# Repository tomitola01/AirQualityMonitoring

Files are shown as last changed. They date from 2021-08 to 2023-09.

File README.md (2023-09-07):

# Air Quality Monitoring System
This repository includes the Arduino C code (monitoring_arduinoC.ino) for the air quality monitoring system. To be used with the ESP32 microcontroller, a BME680 sensor, a push button for input, and an Adafruit 128x32 OLED. <br />
\
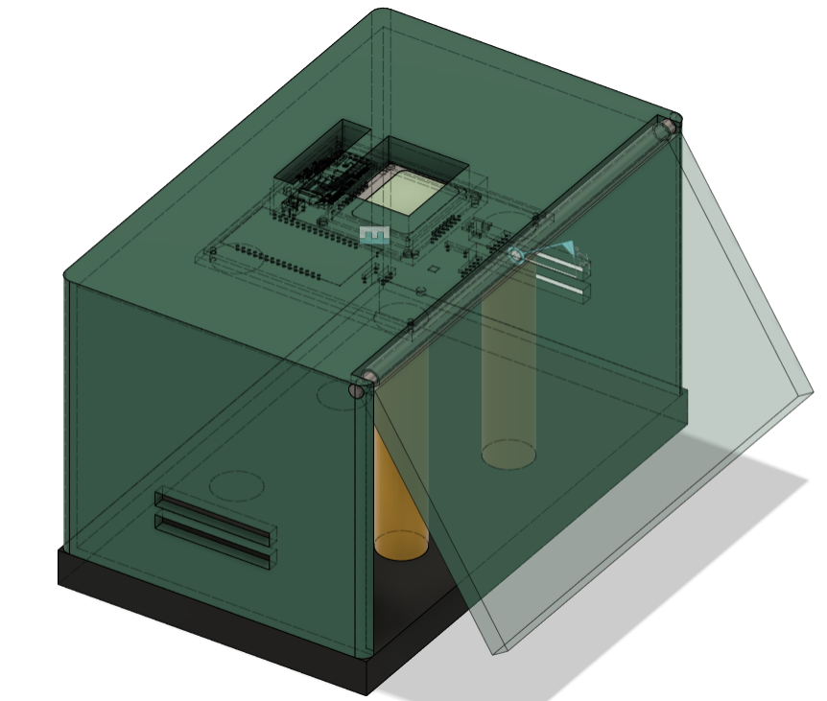
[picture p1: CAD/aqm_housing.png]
Fusion 360 design of the AQM housing
<br/>
\
Below shows the Adafruit display on the breadboard prototype with the system working as expected.
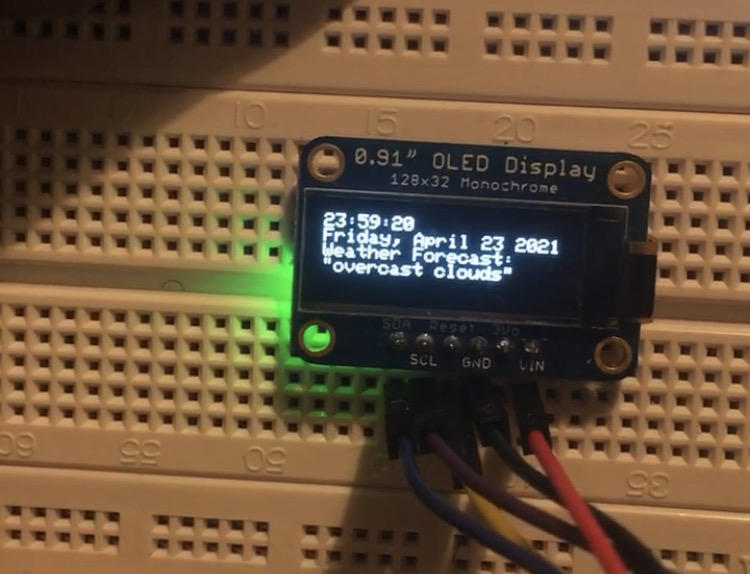
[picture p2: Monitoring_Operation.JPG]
breadboard prototype working on an Adafruit 128x32 shows an example of the system operating normally
<br/>
\
The circuit schematics and PCB for the system can be found in the circuit_files folder. <br />
The CAD folder contains the 3D design of the monitoring system housing. Fusion 360 is needed to open the .fz3 file. <br />
\
Also included is the HTML file (monitoring_webserver.html) to build the web server with the ESP32. <br />
To build the server: 
1. Download the Monitoring_Code folder
2. Open the project using Ardunio
3. Upload the sketch to the ESP32 and run it
4. Open the serial monitor and use obtain the ESP32's IP address
5. Enter IP address into web browser

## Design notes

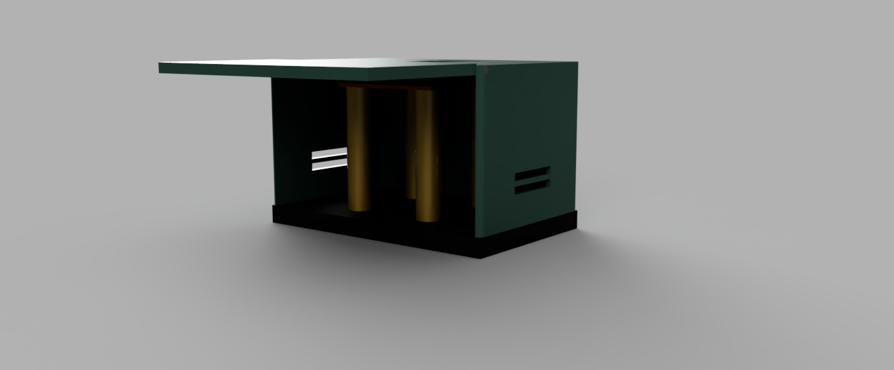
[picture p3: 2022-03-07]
CAD/render.png

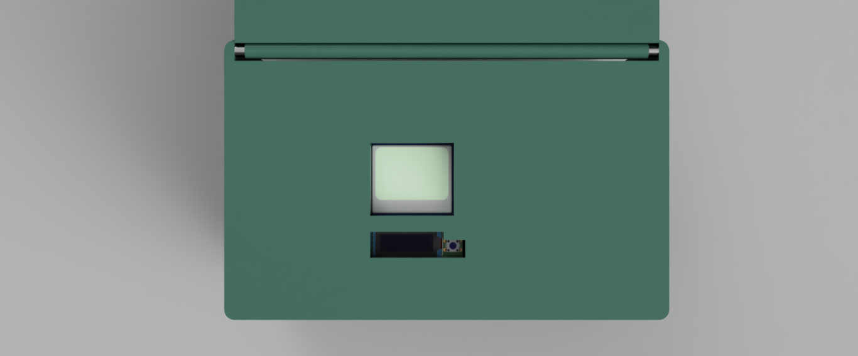
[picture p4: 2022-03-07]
CAD/top render.png

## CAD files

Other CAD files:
CAD/MonitorHousing v15.f3z

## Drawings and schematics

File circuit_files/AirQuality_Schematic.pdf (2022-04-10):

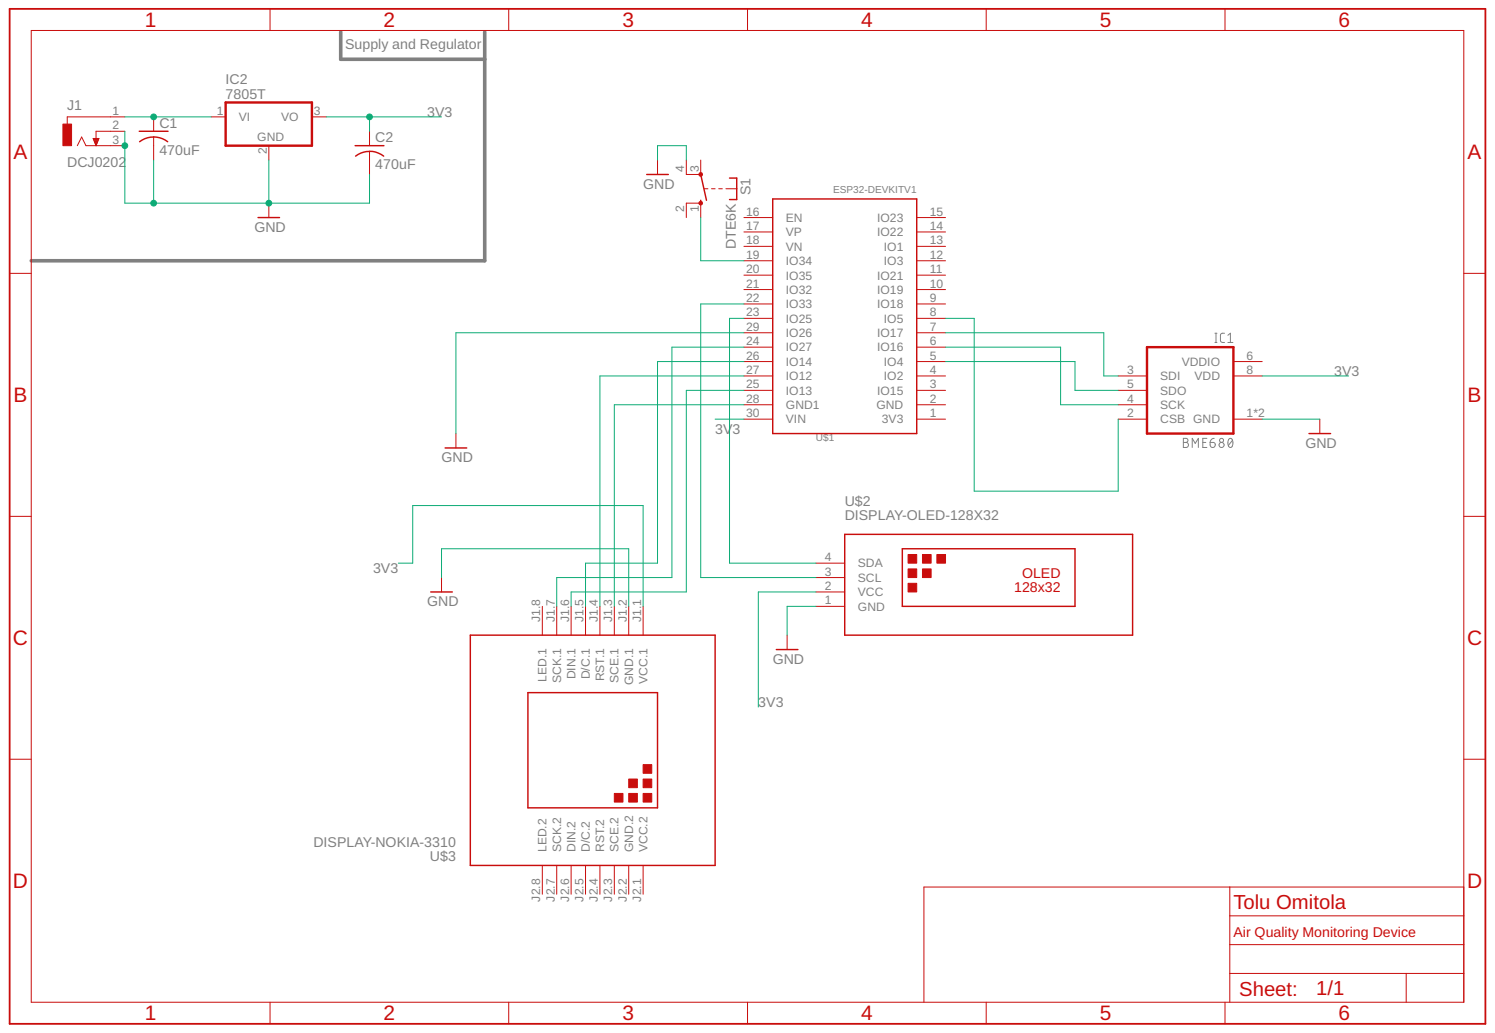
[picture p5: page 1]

IC2 7805T | Supply and Regulator

23 | 8
29 | 7
24 | 6

Air Quality Monitoring Device

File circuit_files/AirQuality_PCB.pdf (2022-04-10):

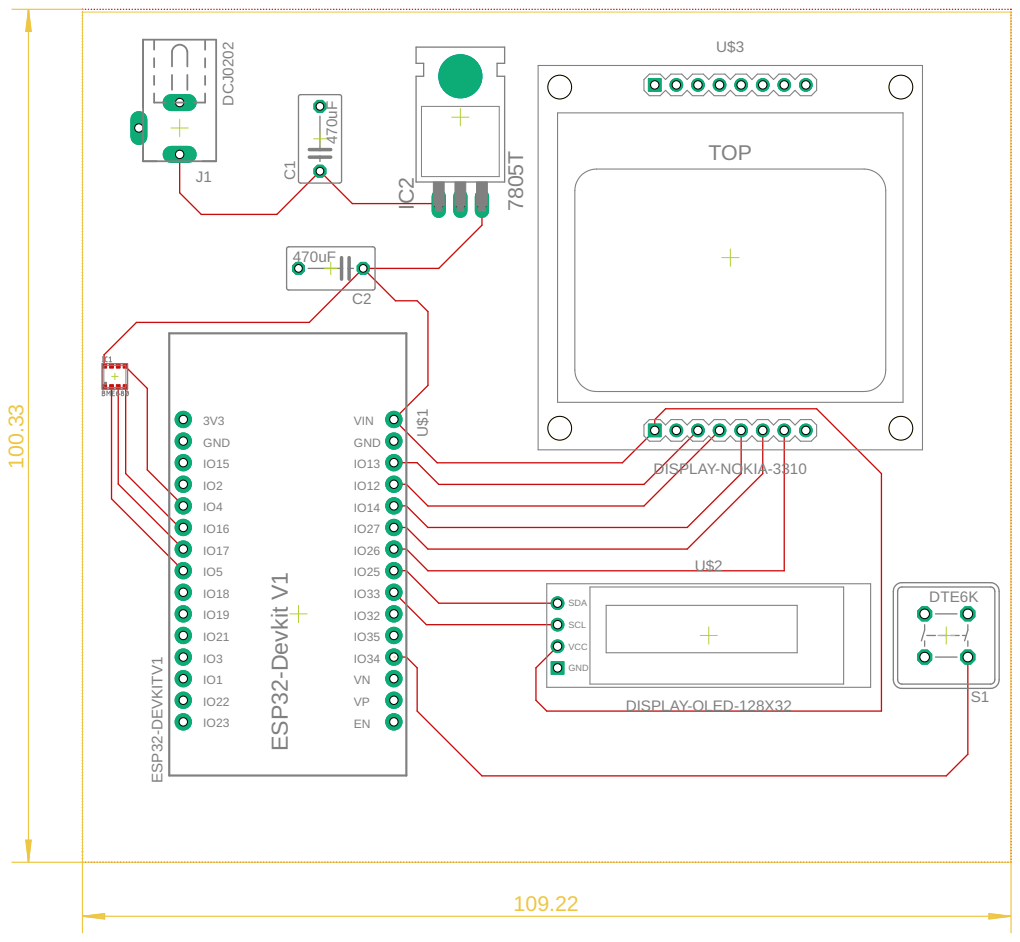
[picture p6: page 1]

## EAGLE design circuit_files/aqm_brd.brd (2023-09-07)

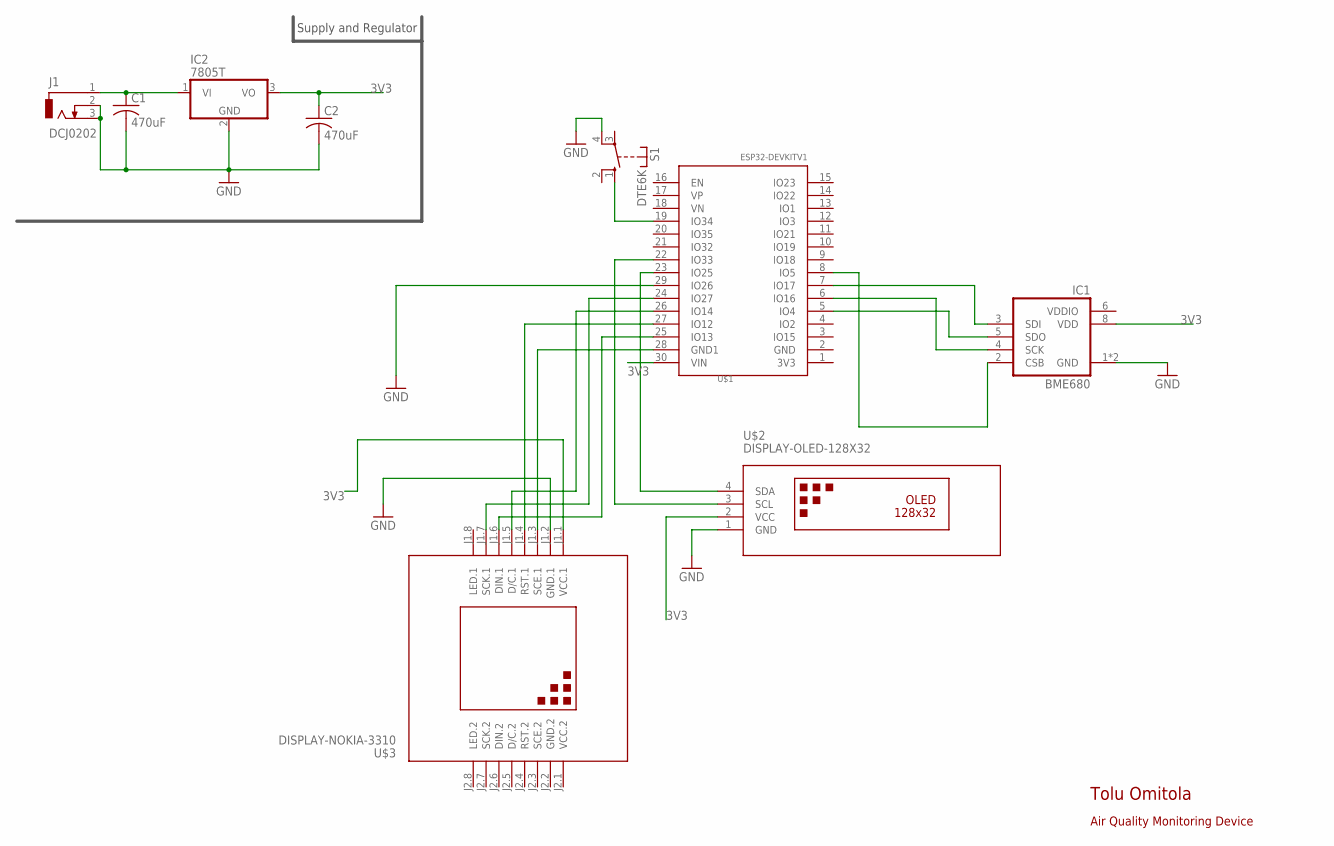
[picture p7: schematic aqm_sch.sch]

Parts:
C1, C2: 470uF; C075-052X106
IC1: BME680
IC2: 7805T; TO220H
J1: DCJ0202
S1: DTE6K
U$1: ESP32DEVKITV1; ESP32-DEVKITV1
U$2: DISPLAY-OLED-128X32
U$3: DISPLAY-NOKIA-3310

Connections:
3V3: C2.1, IC1.8 (VDD), IC2.3 (VO), U$1.30 (VIN), U$2.2 (VCC), U$3.J1.1 (VCC.1)
GND: C1.2, C2.2, IC1.1 (GND), IC1.7 (GND), IC2.2 (GND), J1.2, J1.3, S1.4, U$1.29 (IO26), U$2.1 (GND), U$3.J1.2 (GND.1)
GND.2: U$3.J2.2 (GND.2)
unnamed: U$1.26 (IO14), U$3.J1.5 (D/C.1)
unnamed: U$1.28 (GND1), U$3.J1.3 (SCE.1)
unnamed: U$1.24 (IO27), U$3.J1.7 (SCK.1)
unnamed: U$1.25 (IO13), U$3.J1.6 (DIN.1)
unnamed: C1.1, IC2.1 (VI), J1.1
unnamed: U$1.23 (IO25), U$2.4 (SDA)
unnamed: IC1.2 (CSB), U$1.8 (IO5)
unnamed: U$1.22 (IO33), U$2.3 (SCL)
unnamed: IC1.4 (SCK), U$1.6 (IO16)
unnamed: IC1.5 (SDO), U$1.5 (IO4)
unnamed: U$1.27 (IO12), U$3.J1.4 (RST.1)
unnamed: IC1.3 (SDI), U$1.7 (IO17)
unnamed: S1.1 (S), U$1.19 (IO34)
VCC.2: U$3.J2.1 (VCC.2)
VDDIO: IC1.6 (VDDIO)

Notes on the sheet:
Supply and Regulator
Tolu Omitola
Air Quality Monitoring Device

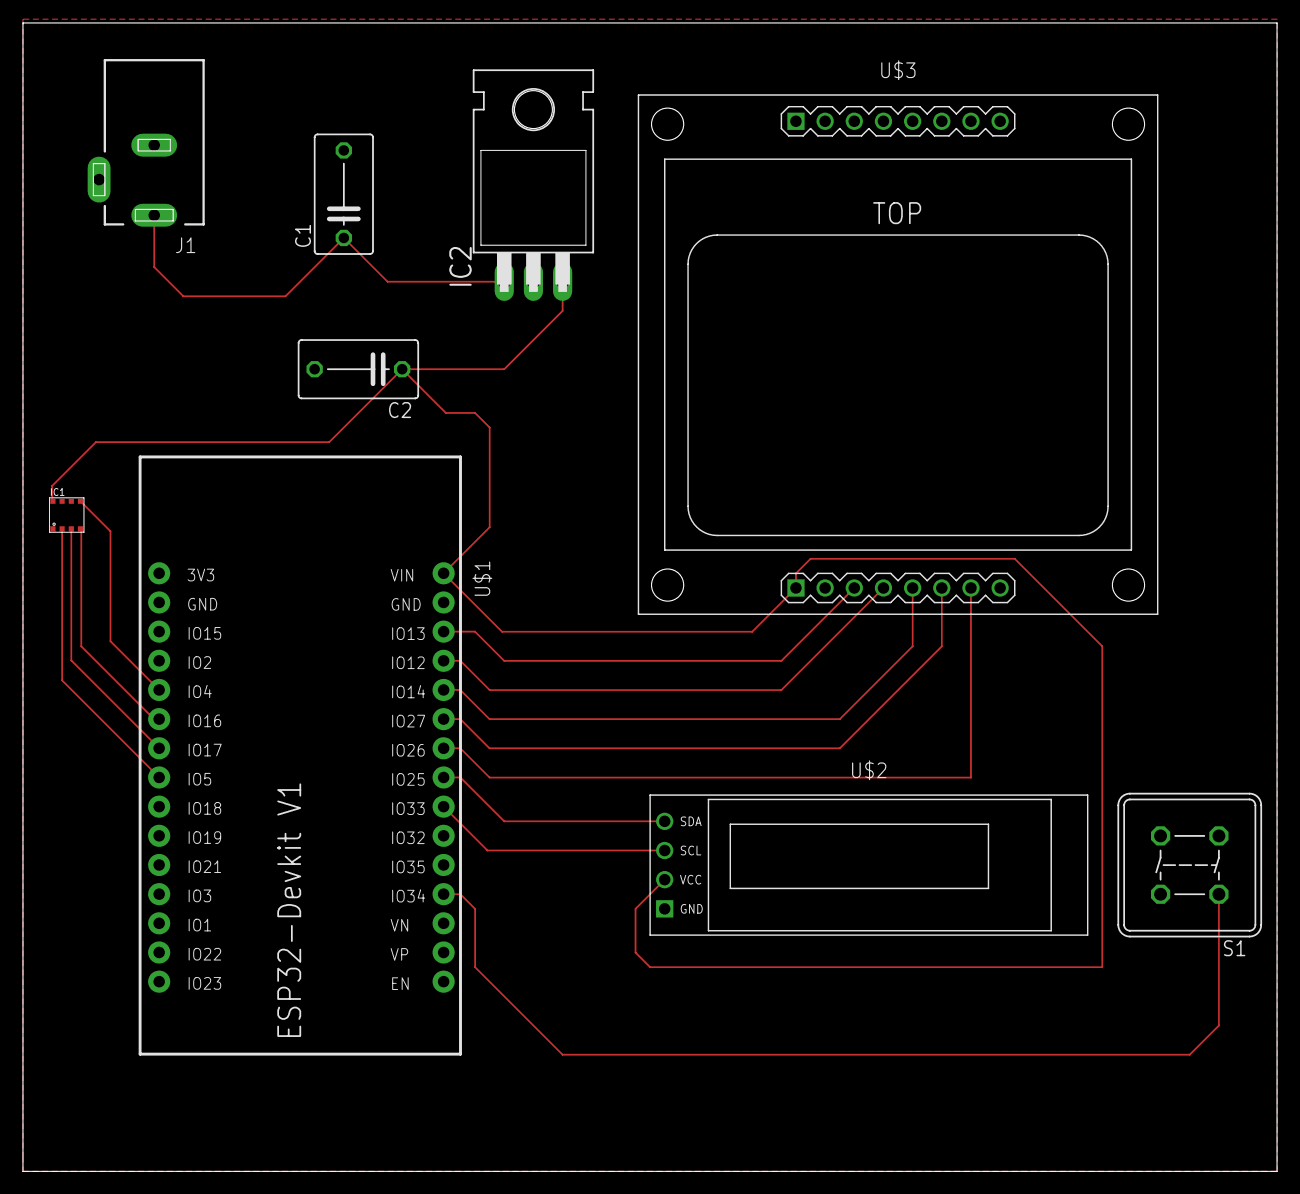
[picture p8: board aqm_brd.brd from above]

Board: 2 copper layers, 109.2 x 100.0 mm, 9 parts (0 on the bottom side), 15 nets.

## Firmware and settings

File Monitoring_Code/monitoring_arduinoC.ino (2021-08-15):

/*
  Code for air quality monitoring system.
  Code heavily adapted using guides from https://randomnerdtutorials.com/projects-esp32/
*/

//libraries included
#include <Wire.h>
#include <SPI.h>
#include <SPIFFS.h>
#include <Adafruit_Sensor.h>
#include "Adafruit_BME680.h"
#include <WiFi.h>
#include "time.h" 
#include <HTTPClient.h>
#include <Arduino_JSON.h>
#include "ESPAsyncWebServer.h"
#include <Adafruit_GFX.h>
#include <Adafruit_SSD1306.h>

//Network credentials
const char* ssid = //enter network SSID;
const char* password = //password for SSID;

//Used to display correct time depending on timezone. Default set to BST.
//Change gmtOffset_sec to desired timezone difference in seconds
//Change daylightOffset_sec if necessary
const char* ntpServer = "pool.ntp.org";
const long  gmtOffset_sec = 0;
const int   daylightOffset_sec = 3600;

String openWeatherMapApiKey = //write free OpenWeatherMap API key here;

String city = //place town/city here
String countryCode = //place country code here

String jsonBuffer;

//define BME connections
#define BME_SCK 18
#define BME_MISO 19
#define BME_MOSI 23
#define BME_CS 15
Adafruit_BME680 bme(BME_CS, BME_MOSI, BME_MISO, BME_SCK);

//define OLED screen connections
#define SCREEN_WIDTH 128 
#define SCREEN_HEIGHT 32 
#define OLED_RESET     17 // Reset pin 
#define SCREEN_ADDRESS 0x3C
Adafruit_SSD1306 display(SCREEN_WIDTH, SCREEN_HEIGHT, &Wire, OLED_RESET);

float temperature;
float humidity;
float pressure;
float gasResistance;

//maximum values for warnings
float maxTemp = 28.0;
float maxHumidity = 70.0;
float maxVOC = 10.0;

bool pressed = false;

AsyncWebServer server(80);
AsyncEventSource events("/events");

//update website, oled and time every second
unsigned long lastTime = 0;  
unsigned long timerDelay = 1000;  // send readings timer

const int button = 16;
int state = 0;

//button interrupt method
void IRAM_ATTR isr() {
  if(state == 0){
    state++;
  }else{
    state = 0;
  }
  pressed = true;
  delay(20);
}

//read bme680 values
void read680Values(){
  unsigned long endTime = bme.beginReading();
  if (endTime == 0) {
    Serial.println(F("Could not begin reading :("));
    return;
  }
  if (!bme.endReading()) {
    Serial.println(F("Could not complete reading :("));
    return;
  }
  temperature = bme.temperature;
  pressure = bme.pressure / 100.0;
  humidity = bme.humidity;
  gasResistance = bme.gas_resistance / 1000.0;
}


void setup() {
  Serial.begin(115200);

  //initialise button interrupt
  pinMode(button, INPUT_PULLUP);
  attachInterrupt(button, isr, RISING);

  // Set the device as a Station and Soft Access Point simultaneously
  WiFi.mode(WIFI_AP_STA);
  
  // Set device as a Wi-Fi Station
  WiFi.begin(ssid, password);
  while (WiFi.status() != WL_CONNECTED) {
    delay(1000);
    Serial.println("Connecting to WiFi Access Point");
  }
  Serial.print("ESP32 Web Server: ");
  Serial.println(WiFi.localIP());
  Serial.println();

  //initialise bme680 sensor
  display.begin(SSD1306_SWITCHCAPVCC, 0x3C);
  display.display();
  delay(100);
  display.clearDisplay();
  display.display();
  display.setTextSize(1);
  display.setTextColor(WHITE);

  //initialise bme680 sensor
  if (!bme.begin()) {
    Serial.println(F("BME680 sensor not connected"));
    while (1);
  }
  //oversampling and filter initialisation
  bme.setTemperatureOversampling(BME680_OS_8X);
  bme.setHumidityOversampling(BME680_OS_2X);
  bme.setPressureOversampling(BME680_OS_4X);
  bme.setIIRFilterSize(BME680_FILTER_SIZE_3);
  bme.setGasHeater(320, 150);

  if(!SPIFFS.begin()){
    Serial.println("Could not mount SPIFFS");
    return;
  }  

  //Web server handling
  server.on("/", HTTP_GET, [](AsyncWebServerRequest *request){
    request->send(SPIFFS, "/index.html");
  });

  //Graphs
  server.on("/temperature", HTTP_GET, [](AsyncWebServerRequest *request){
    request->send_P(200, "text/plain", String(temperature).c_str());
  });
  server.on("/humidity", HTTP_GET, [](AsyncWebServerRequest *request){
    request->send_P(200, "text/plain", String(humidity).c_str());
  });
  server.on("/pressure", HTTP_GET, [](AsyncWebServerRequest *request){
    request->send_P(200, "text/plain", String(pressure).c_str());
  });

  server.on("/resistance", HTTP_GET, [](AsyncWebServerRequest *request){
    request->send_P(200, "text/plain", String(gasResistance).c_str());
  });

  server.begin();

  //initialise time
  configTime(gmtOffset_sec, daylightOffset_sec, ntpServer);
  printTime();
}

void loop() {
    display.setCursor(0,0);
    display.clearDisplay();
    //Sensor warnings
    if(temperature >= maxTemp){
          state = 2;
          pressed = false;
          display.println("Warning: Temperature too high");
          display.display();
        }else if(humidity >= maxHumidity){
          state = 2;
          pressed = false;
          display.println("Warning: Humidity too high");
          display.display();
        }else if((millis()>=10000)&&gasResistance <= maxVOC){
          state = 2;
          pressed = false;
          display.println("Warning: Air quality too low");
          display.display();
    }

    //update website, weather and OLED every second or change OLED display when the button is pressed
    if (((millis() - lastTime) > timerDelay)||pressed == true) {
      read680Values();
      Serial.printf("%.2f, ", temperature);
      Serial.printf("%.2f, ", humidity);
      Serial.printf("%.2f, ", pressure);
      Serial.printf("%.2f ", gasResistance);
      //state 0 displays Time, date, weather and day on OLED
      if(state == 0){
        printTime();
        if(WiFi.status()== WL_CONNECTED){
          String serverPath = "http://api.openweathermap.org/data/2.5/weather?q=" + city + "," + countryCode + "&APPID=" + openWeatherMapApiKey;
          
          jsonBuffer = httpGETRequest(serverPath.c_str());
          Serial.println(jsonBuffer);
          JSONVar myObject = JSON.parse(jsonBuffer);
      
          if (JSON.typeof(myObject) == "undefined") {
            Serial.println("Parsing input failed!");
            return;
          }
          display.println("Weather Forecast: ");
          display.println(myObject["weather"][0]["description"]);
        }
        display.display();
      //state 1 displays BME680 readings on OLED
      }else if(state == 1){
          display.printf("Temperature: %.2f *C\n", temperature);
          display.printf("Humidity: %.2f %%\n", humidity);
          display.printf("Pressure: %.2f hPa\n", pressure);
          display.printf("VOC: %.2f KOhm \n", gasResistance);
          display.display();
      }
      pressed = false;
      Serial.println();
      display.display();
      lastTime = millis();
    }
}

//print time to OLED
void printTime(){
  struct tm timeinfo;
  display.setCursor(0,0);
  display.clearDisplay();
  if(!getLocalTime(&timeinfo)){
    display.println("Failed to obtain time");
    return;
  }
  display.println(&timeinfo, "%H:%M:%S");
  display.println(&timeinfo, "%A, %B %d %Y");
}

//Get data from HTTP to update weaather
String httpGETRequest(const char* serverName) {
  HTTPClient http;
  
  http.begin(serverName);
  
  int httpResponseCode = http.GET();
  
  String payload = "{}"; 
  
  if (httpResponseCode>0) {
    payload = http.getString();
  }
  else {
    Serial.print("Error code: ");
    Serial.println(httpResponseCode);
  }
  http.end();

  return payload;
}

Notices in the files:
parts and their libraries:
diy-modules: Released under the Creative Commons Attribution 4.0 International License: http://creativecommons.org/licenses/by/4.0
